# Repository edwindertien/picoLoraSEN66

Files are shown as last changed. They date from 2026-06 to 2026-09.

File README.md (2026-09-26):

# SEN66 Environmental Monitor

A dual-core Raspberry Pi Pico W environmental sensor node, built for indoor
climate monitoring with an eventual path to beehive deployment. Reads
temperature, humidity, CO2, VOC, NOx and particulate matter from a Sensirion
SEN66, exposes a live web dashboard over WiFi, and transmits sensor data over
LoRa for long-range, low-power telemetry.

System architecture

Startup timeline

## Hardware

| Component | Interface | Pins |
|---|---|---|
| Raspberry Pi Pico W | — | RP2040, dual-core |
| Sensirion SEN66 | I2C0 | SDA=GP4, SCL=GP5, addr 0x6B (SEL→GND) |
| Waveshare Pico-LoRa-SX1262 | SPI1 | SCK=GP10, MOSI=GP11, MISO=GP12, CS=GP3, DIO1=GP20, RST=GP15, BUSY=GP2 |
| Waveshare Pico-LCD-1.14 | SPI1 (shared, see below) | SCK=GP10, MOSI=GP11, CS=GP9, DC=GP8, RST=GP12, BL=GP13 |

The LCD and LoRa shields are stacked on the same header and **share SPI1**
(SCK/MOSI) and, critically, **GP12** — the LCD's RST line and the SX1262's
MISO line are the same physical pin, both hardwired with no jumper option.
Only Button B (GP17) on the LCD's joystick/button cluster is free; every
other button/joystick pin (GP2, GP3, GP15, GP20) collides with an SX1262
signal. See "LCD display and SPI1 sharing" below for how this is resolved.

SEN66 measures PM1.0/2.5/4.0/10, relative humidity, temperature, VOC index,
NOx index, and CO2 (SCD4x). CO2 needs roughly 30s from cold start to produce
a valid reading; fan cleaning (optional, ~11s) blows debris out of the PM
optical chamber and should be enabled for any unattended/production
deployment.

## Software stack

- **VSCode + PlatformIO**, `framework = arduino`, `board_build.core = earlephilhower`
- Platform: `https://github.com/maxgerhardt/platform-raspberrypi.git` (provides
  RP2040/Pico W support including LittleFS and `board = rpipicow`)
- Libraries: `Sensirion I2C SEN66`, `ArduinoJson`, `RadioLib`
- LCD driver (`lcd_driver.h`, `lcd_buttons.h`) is a hand-rolled ST7789 tile-buffer
  driver, adapted from an earlier tonewheel-organ project, not a library dependency

## Architecture

The firmware runs genuinely dual-core. **Core 0** owns WiFi, the web server,
the SEN66 over I2C0, the LittleFS log/config, the serial CLI, and the LCD.
**Core 1** owns the SX1262 over SPI1 — once `setup()` on core 0 completes
(including the SEN66 fan-clean delay), it pushes a release value through the
inter-core FIFO so `setup1()` on core 1 can safely initialise SPI1 and the
radio. This ordering matters: starting SPI1 from core 1 before core 0 has
finished its I2C work caused intermittent CRC errors on sensor reads during
development — see `context.md` for that history, and for the much longer
saga of getting the LCD and radio to share SPI1 at all.

```
src/
  main.cpp        setup()/loop() on core 0, setup1()/loop1() on core 1,
                   serial CLI (incl. net/lora commands), SX1262 Module
                   object (owned here)
  sensor.cpp       SEN66 init/read, sentinel-value handling
  config.cpp       LittleFS config.json load/save
  datalog.cpp      CSV ring-buffer log, /history JSON builder
  wifi_mgr.cpp     STA-with-AP-fallback WiFi bring-up
  http_server.cpp  all web handlers + dashboard/config HTML
  lora_wan.cpp     plain LoRa TX/RX, ACK listen window, radio settings,
                   suspend/resume API for the LCD bus handoff
  lcd_display.cpp  ST7789 page rendering, button handling, SPI1
                   release/reclaim on screen off/on

include/           matching headers (lcd_driver.h, lcd_buttons.h are the
                   hand-rolled ST7789/button drivers, not third-party libs)
data/config.json   default config — upload with `pio run --target uploadfs`
```

## LCD display and SPI1 sharing

The LCD and the LoRa radio are both on SPI1, and — unlike a normal
multi-device SPI bus where each device just gets its own CS pin — the LCD's
RST line and the SX1262's MISO line are the **same physical pin (GP12)**,
hardwired with no way to separate them. RST needs to be a Pico-driven output
held high; MISO needs to be the SX1262's own output, which toggles as a
normal part of any SPI transaction. The two roles cannot coexist on one wire
at the same time.

The working solution is a **coarse-grained bus handoff**: the LCD and the
radio never use SPI1 concurrently, not even briefly. Only one of them owns
the bus at any moment, decided by whether the screen is on or off:

- **Screen off** (the default, low-power "LoRa node" state): the radio runs
  normally — `initLoRa()`/`loopLoRa()` on core 1, streaming or CLI-triggered
  TX as configured. The LCD's SPI1 pins (CS, DC, RST, SCK, MOSI) are all
  explicitly set to `INPUT`, so nothing is left driving GP12 except whatever
  the radio needs.
- **Button press wakes the screen**: `lcd_display.cpp` calls
  `lora_request_suspend()`, then polls `lora_is_suspended()` (up to a 3s
  timeout) before touching any pins. Core 1 sees the request at the top of
  its next `loopLoRa()` call, finishes whatever it's doing, puts the radio
  to sleep, releases SPI1, and sets `suspended = true`. Only then does the
  LCD run a **full** `lcd_init()` — not just a pin reconfiguration, the
  complete hardware-reset-pulse-plus-ST7789-init-sequence, since every pin
  was fully released as an input and there's no partial state to build on.
- **Screen times out (20s) or is cycled to OFF**: the LCD releases SPI1
  (`SPI1.end()` + all pins back to `INPUT`) and calls `lora_request_resume()`.
  Core 1 sees the flag clear and calls `initLoRa()` fresh — a complete
  re-init is simpler and more robust than trying to wake the radio from
  `sleep()` with partial state, and this only happens on the rare event of
  a screen transition, so the cost is negligible.

Button B (GP17, the only free pin — see the hardware table above) is
interrupt-driven rather than polled: a plain `digitalRead()` once per
`loop()` iteration was found to miss short taps whenever `loop()` was
briefly busy (a web request, a page render). The interrupt latches the
press the instant it happens, independent of `loop()` timing.

**LCD pages** (`LcdPage` enum in `lcd_display.h`): `SENSOR` → `WIFI` →
`LORA` → six per-channel graph pages → `OFF`, cycling forward on each
Button B press, wrapping back to `SENSOR` after `OFF`. The `LORA` page
shows `suspend` as its state whenever the radio is suspended for the LCD's
own use (which is always true while you're looking at any other page).

See `context.md` for the full, often painful, history of how this
architecture was arrived at — several plausible-looking fixes (mutex
tuning, per-transaction claim/release, forcing a hardware peripheral reset,
defensively deasserting the other device's CS) were tried and ruled out
before the actual fix (coarse-grained mutual exclusion, never concurrent
access) was found.

## Serial CLI

```
help                      command list
status                     full system + LoRa status
read                       single human-readable sensor reading
stream                     toggle CSV stream (Python-monitor compatible)
debug <n>                  0=off 1=web 2=sensor 4=lora 8=bus (OR-able)

net status                 WiFi mode, SSID, IP
net ssid <name>            set WiFi SSID, saved to flash immediately
net pass <password>        set WiFi password, saved to flash immediately
net reconnect              REBOOTS to apply saved SSID/password — see
                            "Network" below for why this must be a reboot

lora status                radio state, TX count, last ACK (shows
                            "suspend" while the LCD screen is on)
lora send                  TX one sensor packet immediately
lora stream on|off         toggle automatic interval TX
lora test <freq> <msg>     one-shot TX on any frequency, any message
lora freq [mhz]            get/set frequency
lora sf <7-12>              set spreading factor
lora power <2-22>          set TX power, dBm
```

`debug 8` (bus) enables diagnostic logging for the LCD/LoRa SPI1 handoff —
leave it off for normal use, turn it on only when debugging screen-on/off
transitions or radio suspend/resume timing.

## Web interface

- `/` — live dashboard: sensor values, LoRa status with live TX countdown,
  tabbed history graphs (selectable channels and time range, axes labelled)
- `/config` — WiFi, logging, LoRa radio and node settings; saves to
  `config.json` and reboots
- `/log` — download the CSV log
- `/clearlog` — wipe the log
- `/data`, `/history`, `/lorastatus`, `/configjson` — JSON API backing the
  above

WiFi starts in STA mode if `wifi_ssid` is set in config, falling back to AP
mode (`SEN66-Monitor` / `sen66pass`, 192.168.4.1) otherwise. Open the
dashboard with `http://` explicitly — some browsers (Firefox) auto-upgrade
bare hostnames to HTTPS, which a local device cannot serve.

## Network

Set or change WiFi credentials from the serial CLI:
```
net ssid myhomewifi
net pass mypassword
net reconnect
```
`net ssid`/`net pass` save to flash immediately but do **not** take effect
live. `net reconnect` genuinely reboots the device (`rp2040.reboot()`)
rather than trying to re-run WiFi setup in place — this is a deliberate
workaround for an arduino-pico core limitation, not a shortcut we took:
`WiFi.status()`/`WiFi.localIP()` both key off an internal `_apMode` flag
that isn't reliably cleared by switching `WiFi.mode()` at runtime once AP
mode has been used, so a live re-init after an AP fallback can report a
fake instant "connected" using the AP's own IP address instead of a real
DHCP lease from your router (see `context.md` and
[earlephilhower/arduino-pico#762](https://github.com/earlephilhower/arduino-pico/issues/762)).
A full reboot is the only reliable way to get a clean STA connection after
the device has ever been in AP mode during the current power cycle.

## LoRa

Two operating modes, set via `lora_mode` is implicit in which CLI/config path
you use — see `lora_wan.cpp`:

- **Plain LoRa** (current, working) — node-ID-prefixed JSON packets
  (`<SEN66-01>{"t":22.3,...}`), private sync word `0x12` so traffic doesn't
  collide with LoRaWAN gateways on the same frequency, 2-second ACK listen
  window after every TX, hardcoded 30s minimum interval as an EU868 duty
  cycle safety floor regardless of configured `lora_interval_s`.
- **LoRaWAN OTAA** (planned, not yet implemented in this codebase) — will
  join via OTAA and send Cayenne LPP payloads to a self-hosted ChirpStack
  gateway, which republishes decoded uplinks to MQTT for Node-RED/Grafana
  consumption.

Config fields: `lora_freq`, `lora_sf`, `lora_bw`, `lora_power`,
`lora_interval_s`, `lora_stream`, `node_id`. LoRaWAN credential fields
(`lora_dev_eui`, `lora_app_eui`, `lora_app_key`) are present in config but
unused until Phase B is built.

## Known limitations / next steps

- LoRaWAN OTAA join is not yet implemented in the current `lora_wan.cpp` —
  only plain peer-to-peer LoRa works today.
- PM optics can read saturated (`0xEB00` sentinel, shown as `SAT` in the UI)
  if the sensor is freshly unboxed, the inlet sticker is still attached, or
  airflow is otherwise obstructed — this is sensor behaviour, not a firmware
  bug.
- The 30s LoRa duty-cycle floor is a flat safety constant, not a proper
  airtime calculation from SF/BW/payload size. Adequate for EU868 at SF9 with
  these short payloads, but should be revisited before scaling to many
  nodes or larger payloads.
- `net reconnect` (and any future WiFi credential change) requires a reboot
  to take effect, by design — see "Network" above. There is currently no
  way to switch STA→AP→STA within one power cycle and get a genuine DHCP
  lease; don't try to "fix" this with a live `startWiFi()` re-init, it's
  been tried and doesn't work on this platform.
- The LCD cannot show live data and the radio cannot transmit at the same
  instant — this is intentional (see "LCD display and SPI1 sharing"), not
  a bug to fix. If simultaneous LCD+radio operation is ever needed, it
  would require moving one of them off SPI1 entirely (e.g. a different LCD
  interface) rather than trying to time-slice the shared bus more finely
  than we already tried and failed to do.
- See `context.md` for the full development/debugging history, including
  several substantial false starts that are deliberately documented so
  they aren't repeated.

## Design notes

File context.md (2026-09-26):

# Development context / handoff notes

This document exists so the next debugging session (human or AI) doesn't
repeat the same dead ends. Read this before changing `lora_wan.cpp`,
`main.cpp`'s core split, `sensor.cpp`'s init sequence, `lcd_display.cpp`/
`lcd_driver.h` (see "The LCD/SPI1 sharing saga" — by far the longest and
most expensive section here), or `wifi_mgr.cpp`'s reconnect behaviour (see
"Network").

## Project phases, in order

1. SEN66 over I2C → serial CSV (Phase 1) — straightforward, worked first try
   once the Sensirion library's `NO_ERROR` macro and integer-vs-float
   signature issues were sorted out.
2. Python live visualiser (`sen66_monitor.py`) — matplotlib, mirrors the
   serial CSV format so it works unchanged against later firmware phases.
3. Web dashboard, AP + STA WiFi, LittleFS config/log, tabbed graph UI
   (Phase 2) — the bulk of the working single-core baseline.
4. Dual-core LoRa integration — this took many iterations to get right; see
   below.
5. Waveshare Pico-LCD-1.14 menu (sensor/WiFi/LoRa status pages, per-channel
   graphs, Button B navigation) — took *even more* iterations, almost all
   of it about sharing SPI1 with the already-working LoRa radio; see "The
   LCD/SPI1 sharing saga" below. This is the single longest debugging arc
   in the project's history — read that section before touching
   `lcd_display.cpp`, `lcd_driver.h`, or the radio suspend/resume API in
   `lora_wan.cpp`.

## The dual-core LoRa saga — what went wrong and why

The single biggest source of wasted time was **CRC errors on SEN66 reads**
that appeared only after LoRa/dual-core code was added, despite the SEN66
sitting on a completely separate bus (I2C0, GP4/GP5) from the LoRa radio
(SPI1, GP10/11/12). Several false theories were chased before finding the
real cause:

### False theory 1: electrical noise from the LoRa shield
Suspected the stacked shield was coupling noise onto the I2C lines, or that
the SX1262 PA current spike was drooping the 3.3V rail enough to glitch I2C.
**Ruled out** — the user confirmed no hardware had changed between a working
single-core build and a failing dual-core build with identical wiring.

### False theory 2: GPIO interrupt collision
GP20 (DIO1, the SX1262 IRQ pin) is also a valid I2C0 SDA alternate function
on the RP2040. Theorised that RadioLib's `attachInterrupt()` on GP20 was
corrupting I2C0 transactions on GP4 via shared interrupt controller state.
Tried `radio.clearDio1Action()` to force polling instead of interrupts.
**Did not fix it** — the CRC errors persisted even with the interrupt
cleared, so this was at most a minor contributor, not the root cause.

### False theory 3: core 1 spinning too fast
Tried `__wfi()`, `sleep_ms()`, and various busy-wait patterns in `loop1()`,
theorising that core 1 polling too aggressively was starving core 0 of bus
cycles. **Did not fix it.**

### Actual root cause: enlarging `Config` and including `config.h` in `sensor.cpp`
The real cause was much simpler and had nothing to do with cores or
interrupts at all: **`sensor.cpp` had gained an `#include "config.h"`**
during a refactor that added LoRa fields to the `Config` struct. Enlarging
`Config` changed stack/memory layout in a way that corrupted something
adjacent — likely the ArduinoJson `JsonDocument` or the SEN66 I2C read
buffer — when both were compiled in the same translation unit as the now-
larger struct.

**The fix:** `sensor.cpp` must never include `config.h`. Anything `sensor.cpp`
needs from config (e.g. whether to run fan cleaning) is passed in as a plain
function parameter from `main.cpp`, which does have `config.h`:

```cpp
// sensor.h
void initSensor(bool doFanCleaning = true);

// main.cpp
initSensor(cfg.fan_cleaning);
```

This was confirmed by diffing against a known-good single-core project
(`picoSEN66_3`) file-by-file and restoring files verbatim, then re-adding
LoRa support field-by-field while explicitly checking `sensor.cpp` for stray
includes after every change.

**Lesson for future work:** if CRC/I2C errors reappear after adding fields
to `Config`, check `sensor.cpp`'s includes before suspecting hardware,
interrupts, or core timing. It is tempting to blame dual-core because the
symptom only appeared after dual-core was introduced, but the actual trigger
was a coincident refactor, not the cores themselves.

### SPI1 init pattern that actually works

Earle Philhower's `SPIClassRP2040` (not `arduino::MbedSPI` — that class
doesn't exist in this core, despite appearing in some other projects'
examples found online) needs pins set individually before `begin()`:

```cpp
SPI1.setRX(12);     // MISO
SPI1.setTX(11);     // MOSI
SPI1.setSCK(10);    // SCK
SPI1.begin(false);  // false = software/manual CS; RadioLib drives CS (GP3)
                     // directly as a GPIO, so setCS() is never called
```

Calling `setCS()` was tried and is unnecessary — RadioLib's `Module`
constructor takes the CS pin directly and manages it itself.

**Ownership rule that was eventually settled on:** all SPI1 setup
(`setRX/setTX/setSCK/begin`) and `radio.begin()` happen together on **core
1**, inside `setup1()`, gated by `rp2040.fifo.pop()` so core 1 doesn't touch
SPI1 until core 0 has explicitly signalled (via `rp2040.fifo.push()`) that
its own setup — including the SEN66 fan-clean delay — is fully complete.
Earlier attempts split SPI1 init across both cores or ran it before core 0
finished; both caused hangs or the CRC corruption above.

### `radio.begin()` parameter gotchas

- Calling `radio.begin()` with explicit TCXO voltage (`tcxoVoltage` param)
  caused indefinite hangs on this Waveshare module — it sends a
  `SetDIO3AsTCXOCtrl` command and waits for oscillator lock that never
  completes on this hardware. **Fix:** call `radio.begin()` with no
  arguments (defaults), then explicitly call `setFrequency`, `setBandwidth`,
  `setSpreadingFactor`, `setCodingRate`, `setSyncWord`, `setOutputPower`
  afterward.
- `radio.setDio2AsRfSwitch(true)` is required for this module's RF switch
  wiring.
- RadioLib's `LoRaWANNode::beginOTAA()` signature changed between major
  versions — v6.x takes `uint64_t joinEUI, uint64_t devEUI, uint8_t* nwkKey,
  uint8_t* appKey` and returns `void` (not `int16_t`). EUIs must be parsed
  from hex strings to `uint64_t`, not byte arrays, for this call.

## Duty cycle / interval bug

`lora_interval_s` in config and a separate hardcoded `MIN_INTERVAL_MS`
(originally 30000) were both gating LoRa stream timing, and at one point a
manual `lora send` CLI command was *also* gated by the same 30s floor,
making manual testing feel like the firmware was "hanging" for half a minute
on every test send. Resolved by keeping the 30s floor as a safety constant
for **automatic stream mode only** — manual `lora send`/`lora test` should
remain ungated for responsive testing, *however* the user's preference,
confirmed in conversation, was to keep `lora send` gated too (so the
behaviour matches stream mode exactly) once duty cycle and config interval
mismatches were untangled. Current behaviour: `lora send` respects
`dutyOk()`; only `lora test` (explicit one-shot with arbitrary frequency)
bypasses it.

## `lora test` vs `lora send` payload difference

Early in testing, `lora test <freq> <quoted-json>` worked (verified on a
spectrum analyser) while `lora send` did not appear to arrive at the
gateway, despite both reporting `TX OK` at the radio level. Investigation
showed:
- Frequency, SF, BW, and power were identical for both paths once `cfg.lora_freq`
  was set to match the test frequency permanently (rather than being
  temporarily overridden and restored by `lora test`'s save/restore logic).
- The actual unresolved variable when this was last discussed was the
  **30-second duty-cycle wait** being mistaken for a hang — `lora send`
  appeared to "block" because the CLI was reporting `[lora] Duty cycle: wait
  Xs` and the user was watching it count down, not because of a code defect.
  **Status: revisit this if it recurs** — the immediate suspects (frequency
  drift, payload encoding, quoting artefacts) were all ruled out, but a full
  root-cause was not conclusively nailed down before the session moved on to
  other features. If `lora send` silently fails to reach the gateway again,
  capture the gateway-side raw packet log (frequency, SF, payload bytes) for
  a TX that the firmware reports as successful, and compare byte-for-byte
  against a known-good `lora test` packet.

## SEN66 fan cleaning / sensor warm-up

- CO2 (SCD4x inside the SEN66) needs **roughly 30 seconds** from cold start
  to produce a non-sentinel reading — this is sensor physics, not a
  firmware bug. Don't chase "CO2 reads 0/0xFFFF" issues for the first
  30-60s after boot.
- Fan cleaning (`startFanCleaning()`, ~11s) was originally unconditional;
  made it a config-controlled boolean (`fan_cleaning`, default `true`) so it
  can be disabled during rapid iterate-flash-test debugging cycles without
  losing 11 seconds every boot. **Always re-enable for real deployment** —
  without it, PM optics accumulate debris over time.
- One debugging session found the fan was *not spinning* despite
  `startFanCleaning()` reporting no I2C error. Root cause was that
  `startContinuousMeasurement()`'s return value wasn't being checked/logged
  loudly enough to notice it had failed; once explicit
  `Serial.println("[sen66] startContinuousMeasurement OK")` /
  `"FATAL: measurement not started"` logging was added, the failure became
  visible immediately. Always check this log line first if gas-sensor
  channels read zero indefinitely past the 30-60s warm-up window.
- An I2C bus scan (addresses 1-127) was added to `initSensor()` for the same
  reason — confirms the SEN66 is physically present at `0x6B` before doing
  anything else, removing wiring/address as a variable early.

## Files restored from a known-good snapshot

At one point the project was reset to a known-working baseline
(`picoSEN66_3`, single-core, no LoRa) after too many compounding theories
made the dual-core+LoRa debugging session unproductive. All `src/*.cpp` and
`include/*.h` files were diffed and copied verbatim from that baseline
before LoRa was re-added incrementally, one verified step at a time:
1. Dual-core skeleton, core 1 idle (`sleep_ms` only) — confirmed sensor
   still worked.
2. SPI1 pin setup + `begin()` on core 1 — confirmed no hang.
3. `radio.begin()` added — confirmed `SX1262 OK`.
4. CLI-triggered single test TX (`lora test`) — confirmed over spectrum
   analyser.
5. Full plain-LoRa implementation with ACK window, stream mode, settings
   commands.

If dual-core/LoRa breaks again in a way that resists debugging, this
incremental rebuild path (idle core → SPI → radio.begin → manual TX →
full feature) is the fastest way back to a working state — faster than
trying to debug forward from a broken full-featured state.

## The LCD/SPI1 sharing saga

Adding a Waveshare Pico-LCD-1.14 (for a menu of sensor/WiFi/LoRa status
pages plus per-channel graphs) turned into by far the longest debugging
arc in this project — much longer than the dual-core CRC saga above. This
section exists specifically so nobody re-tries the things that were
already tried and ruled out.

### The core physical constraint

The LCD and the SX1262 both sit on SPI1. Sharing SCK/MOSI with separate CS
pins is completely normal and was never the issue. The actual problem is
that **the LCD's RST pin and the SX1262's MISO pin are the same physical
wire (GP12)**, hardwired on both shields with no jumper to separate them.
RST needs to be a Pico output held HIGH; MISO needs to be the SX1262's own
output, which necessarily toggles as part of any normal SPI transaction.
These two roles are fundamentally incompatible on one wire at the same
time — this was eventually understood to be an *electrical* constraint,
not something any amount of clever software timing could paper over.

### Symptom, for a long stretch: "radio works, LCD shows nothing" or vice versa

For many iterations, exactly one of the two would work at a time, and
fixing one reliably broke the other. Everything below was tried, in
roughly this order, while chasing that symptom:

1. **Mutex timing** (`mutex_init()` too late, blocking vs
   `mutex_try_enter`) — no effect on the underlying problem. A flush-
   success/skip counter was added at one point and showed **thousands of
   successful tile flushes with zero visible content** — proof that "the
   function call completed" and "the display actually updated" are not
   the same thing, and that mutex contention was never the bottleneck.
2. **SPI clock speed not being restored** between the LCD's 62.5MHz and
   RadioLib's 2MHz — tried manual `beginTransaction`/`endTransaction`
   restores, then a `radio.setSPISettings()` call that doesn't exist on
   `SX1262` (compile error, reverted), then a manual `spi1_radio_speed()`
   helper. No effect.
3. **GP12 pin-restore mechanism** — tried `SPI1.setRX()` + a second
   `begin()`, then the raw SDK `gpio_set_function()` call instead. Radio
   reliability tracked with *whether the radio ran at all*, not with which
   restore mechanism was used — this was a real clue that got
   under-weighted at the time.
4. **Double `SPI1.begin()` from both cores** — a real and worth-
   remembering finding: SPI1 is **one physical peripheral**, not
   duplicated per core, and having both core 0 (LCD) and core 1 (radio)
   independently call `begin()` does re-initialise the shared block out
   from under whichever side didn't call it last. Removing the second
   `begin()` (radio trusting the LCD's earlier init) fixed radio
   reliability — but the LCD *still* showed nothing afterward, which in
   hindsight proved this was never sufficient on its own.
5. **Full claim/release around every single operation**
   (`SPI1.end()`→reconfigure→`begin()`→work→`end()`, both sides,
   symmetric) — implemented thoroughly, including a genuine RP2040
   `reset_block(RESETS_RESET_SPI1_BITS)`/`unreset_block_wait(...)`
   hardware peripheral reset (not just the `SPI1.end()`/`begin()` Arduino
   wrapper, which does not guarantee every internal register returns to
   power-on defaults). Radio kept working; LCD still showed nothing.
6. **Defensively deasserting the other device's CS** before every claim
   (force GP3 HIGH before an LCD transfer, GP9 HIGH before a radio
   transfer) — on the theory that a stuck-low CS was letting the SX1262
   "listen in" on LCD traffic and corrupt it. No change.
7. **RadioLib's DIO1 interrupt** — `radio.clearDio1Action()` had been
   added, then lost, then re-added; a genuinely different mechanism from
   everything else (an ISR firing outside the mutex model entirely), but
   also made no difference to the LCD-blank symptom specifically.

### The reset that actually mattered: going back to a known-good baseline

After enough failed fixes, the productive move was to **stop iterating on
the broken integrated system** and rebuild forward from a state that was
provably correct:

1. Restored `lcd_driver.h`'s `lcd_init()` to the exact version that had
   been confirmed rendering correctly early on — the LCD calling its
   **own** `SPI1.begin()` (no arguments — hardware CS mode), with a real
   hardware RST pulse on GP12. This intentionally reintroduces the GP12
   conflict, on the theory that the *sharing model*, not this specific
   pin, was the real problem.
2. Rebuilt `lcd_display.cpp` from scratch as a deliberately minimal,
   single-core-only baseline: no radio code compiled in at all (`main.cpp`
   with an empty `setup1()`/`loop1()`, `lora_wan.cpp` moved out of `src/`
   entirely so it isn't even linked). Confirmed the LCD worked reliably,
   permanently on, through many pages and power cycles, with radio fully
   out of the picture.
3. Added the screen timeout and OFF-page cycling *before* touching the
   radio again, confirming the LCD's own release-to-`INPUT` and full-
   `lcd_init()`-on-wake cycle was solid in isolation — still zero radio
   involvement.
4. Only then reintroduced LoRa, with a **coarse-grained bus handoff**
   instead of any of the fine-grained per-transaction sharing tried
   before: the LCD and radio never touch SPI1 concurrently, not even
   briefly. Whoever isn't currently "in control" doesn't merely yield the
   bus for a moment — it's either fully active or fully torn down
   (`SPI1.end()` + every pin to `INPUT` on the LCD side; `radio.sleep()`
   + release on the radio side), with a simple request/acknowledge flag
   pair (`lora_request_suspend()`/`lora_is_suspended()`/
   `lora_request_resume()`) governing the handoff. This is the
   architecture described in the README and is what actually works.

**The lesson, stated plainly:** fine-grained interleaving of two devices
on a bus that share a physical pin with genuinely incompatible signal
roles cannot be made to work by better mutex discipline, faster resets, or
more careful timing — no matter how many different mechanisms you try. It
needs coarse-grained mutual exclusion: one owner at a time, full teardown
on handoff, never both "on" simultaneously even for a moment.

### Two compounding bugs that wasted significant time mid-saga

- **A file mix-up**: at one point `src/lcd_display.cpp` on the user's
  actual disk had accidentally ended up containing `main.cpp`'s content
  (duplicate `setup()`/`loop()`, global variables, linker errors like
  "multiple definition of `staMode`"). This produced confusing symptoms
  that looked like a code regression but were actually just the wrong
  file being compiled. **Lesson**: when behaviour doesn't match what the
  source clearly says it should do, check for a stale build or a
  misplaced file *before* forming a new theory about the code's logic.
- **A leftover diagnostic flag**: `LORA_FULLY_DISABLED` (added
  temporarily to isolate whether LoRa activity was blocking LCD
  rendering) was left defined for several turns after it had served its
  purpose, causing `lora_is_suspended()` to unconditionally return `true`
  and completely masking the real suspend/resume logic — producing
  exactly the "LCD always active, radio always suspended" symptom, with
  no relation to the actual bug being chased at the time. **Lesson**:
  temporary isolation flags need to be actively removed, not just left
  commented-out-by-default, and their effect should be the first thing
  checked when a symptom looks suspiciously absolute ("always", "never").

### Smaller fixes bundled into the same rebuild

- **Button B polling missed short presses.** A plain `digitalRead()` once
  per `loop()` iteration can miss a tap that starts and ends between two
  loop iterations, if `loop()` happens to be briefly busy (a web request,
  a page render's SPI transfer). Switched to `attachInterrupt()` with a
  50ms debounce inside the ISR itself — the press is latched the instant
  it happens, independent of `loop()` timing.
- **The OFF page was unreachable.** The page-cycle wrap logic checked "did
  we overflow past `PAGE_COUNT`, if so reset to `SENSOR`" *before*
  checking "did we land exactly on `OFF`" — so the overflow check always
  fired first and the OFF-check could never be reached. Fixed with a
  plain modulo wrap (`OFF` is enum value `0`, so `(current + 1) %
  PAGE_COUNT` lands there correctly on its own).
- **Default boot state changed** to screen-off/backlight-off/LoRa-active
  — the device is meant to operate as a low-power LoRa node most of the
  time, with the screen only for occasional interactive checks. The LCD
  hardware isn't even touched at boot now (no `lcd_init()` call at all
  until the first button press) specifically so the radio gets a
  completely untouched SPI1 peripheral as its first-ever user.

## Network: `_apMode` and why `net reconnect` must reboot

Adding `net ssid`/`net pass`/`net reconnect` CLI commands surfaced a
genuine arduino-pico core bug, not an application-level mistake:
[earlephilhower/arduino-pico#762](https://github.com/earlephilhower/arduino-pico/issues/762).
`WiFiClass::status()` and `WiFiClass::localIP()` both decide which
physical interface (STA vs AP) to report on via an internal `_apMode`
boolean, which is not reliably cleared by calling `WiFi.mode()` at
runtime once AP mode has been used. Symptom observed directly: after a
STA-failed→AP-fallback at boot, calling `net reconnect` (which re-ran
`startWiFi()` live) produced:
```
[wifi] Trying STA: voorhuis
[wifi] Connected! IP: 192.168.42.1
```
— note zero connection-attempt dots (a real STA handshake takes at least
a few hundred ms; here `WL_CONNECTED` was reported instantly) and an IP
identical to the AP's own address, not a real DHCP lease from the router.
Things tried that did **not** fix it: `WiFi.disconnect(true)` before
retrying (helped nothing since the flag itself wasn't touched),
`WiFi.softAPdisconnect(true)` + `WiFi.mode(WIFI_OFF)` + a settling delay
before retrying STA (still no change — `_apMode` apparently isn't cleared
by any combination of these calls). **The only fix that actually works**:
`net reconnect` now calls `rp2040.reboot()` outright. A full reboot
reinitialises the WiFi driver and its `_apMode` flag from a genuinely
clean state; nothing short of that was found to be reliable. Don't spend
time trying to find a live-reinit workaround again without checking
whether upstream has fixed the underlying issue first.

## Outstanding / not yet built

- LoRaWAN OTAA join + Cayenne LPP uplinks (Phase B) — config fields exist,
  implementation does not yet.
- ChirpStack gateway setup, MQTT integration, Node-RED/Grafana consumption —
  not started.
- Proper duty-cycle calculation from SF/BW/payload size (currently a flat
  30s constant).
- The `lora test` vs `lora send` gateway-arrival discrepancy noted above —
  inconclusively resolved, revisit if it recurs.
- Joystick/A-button support while the screen is on: now that the radio is
  fully suspended (and its pins inert) whenever the LCD is active, GP2/GP3/
  GP15/GP20 are technically free for the joystick during that window —
  this was identified as a natural follow-on but not yet implemented. Would
  need those pins reconfigured to `INPUT_PULLUP` on wake and handed back to
  the radio's expected states on sleep, mirroring what's already done for
  the LCD's own pins.
- LCD/radio genuinely simultaneous operation is not supported by design
  (see "LCD display and SPI1 sharing" in the README) — don't attempt to
  relax this without first re-reading the saga above.

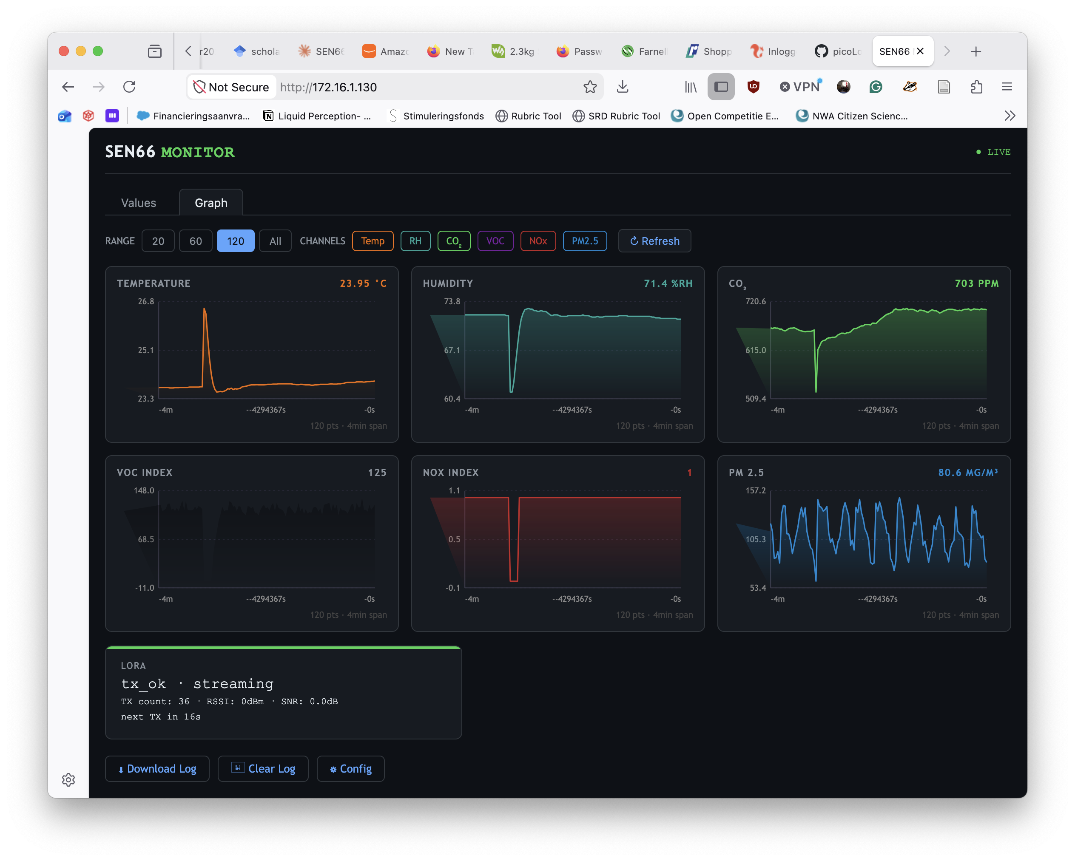
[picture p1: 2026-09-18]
docs/interface.png

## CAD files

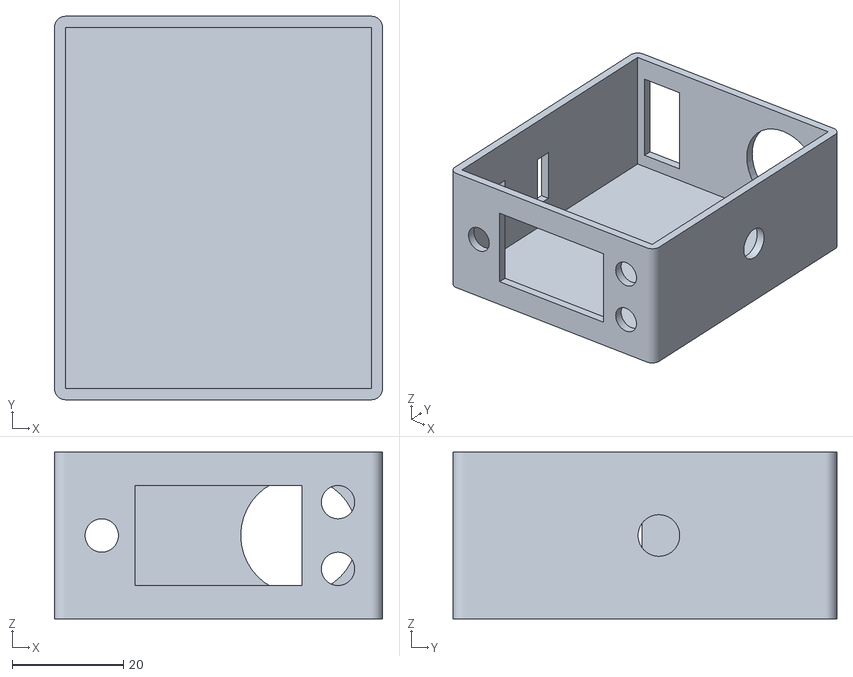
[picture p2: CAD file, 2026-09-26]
design/box.stl
59.0 x 69.0 x 30.0

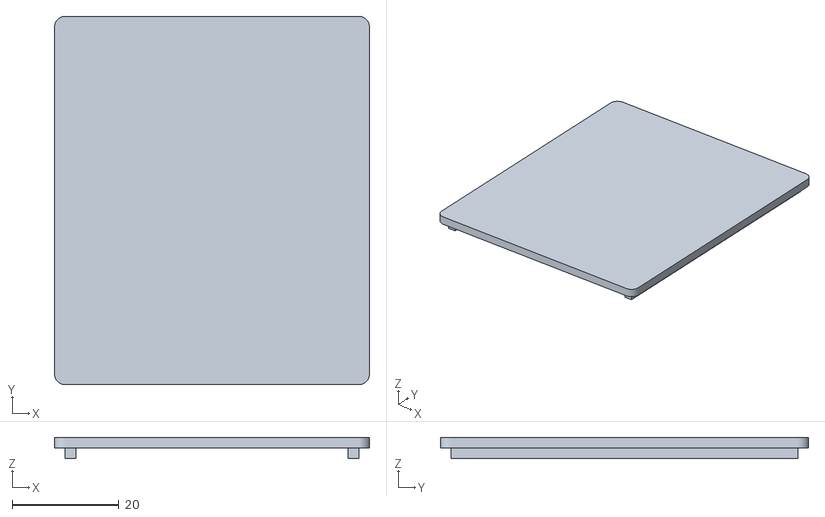
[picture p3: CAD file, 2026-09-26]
design/lid.stl
59.0 x 69.0 x 4.00

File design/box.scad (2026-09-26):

$fn=40;

box(55,65,28,2);

//translate([0,0,40])lid(55,70,2);

module box(width, depth, height,wall){
difference(){
    hull(){
        translate([0,depth,0])cylinder(r=wall,h=height+wall);
        translate([width,depth,0])cylinder(r=wall,h=height+wall);
        translate([width,0,0])cylinder(r=wall,h=height+wall);
        translate([0,0,0])cylinder(r=wall,h=height+wall);
    }
    translate([0,0,wall])cube([width,depth,height+wall]);
    
    translate([42,50,15])rotate([-90,0,0])cylinder(d=21,h=30);
    translate([2,50,5])cube([10,30,20]);
    
    translate([12.5,-5,6])cube([30,30,18]);
    
    translate([49,-5,9])rotate([-90,0,0])cylinder(d=6,h=30);
    translate([49,-5,21])rotate([-90,0,0])cylinder(d=6,h=30);
    translate([6.5,-5,15])rotate([-90,0,0])cylinder(d=6,h=30);
    translate([-5,28,8])cube([20,4,12]);
    translate([-5,12,12])cube([20,4,8]);
    
    translate([25,35,15])rotate([0,90,0])cylinder(d=7.5,h=50);
}
}


module lid(width, depth,wall){
difference(){
    hull(){
        translate([0,depth,0])cylinder(r=wall,h=wall);
        translate([width,depth,0])cylinder(r=wall,h=wall);
        translate([width,0,0])cylinder(r=wall,h=wall);
        translate([0,0,0])cylinder(r=wall,h=wall);
    }
}
difference(){
translate([0,0,-wall])cube([width,depth,wall]);
    translate([wall,0,-wall])cube([width-2*wall,depth,wall]);
}
}

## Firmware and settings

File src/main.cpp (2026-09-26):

// ═══════════════════════════════════════════════════════════════════════════
// SEN66 Monitor — Step 3: LCD + LoRa reintegrated
// Core 0: WiFi, web, sensor, serial CLI, LCD
// Core 1: LoRa — suspended/resumed via coarse-grained bus handoff whenever
//         the LCD screen is on/off (see lora_request_suspend/resume calls
//         in lcd_display.cpp's screen_on_page()/screen_off()).
// ═══════════════════════════════════════════════════════════════════════════
#include <Arduino.h>
#include <LittleFS.h>
#include <WiFi.h>
#include <WebServer.h>
#include <SPI.h>
#include <RadioLib.h>

#include "globals.h"
#include "config.h"
#include "sensor.h"
#include "datalog.h"
#include "wifi_mgr.h"
#include "http_server.h"
#include "lora_wan.h"
#include "lcd_display.h"

uint8_t  debugLevel    = 0;
bool     streamEnabled = false;
bool     staMode       = false;
uint32_t lastLogTime   = 0;

// ── SX1262 radio object — owned by core 1 ────────────────────────────────
// Waveshare Pico-LoRa-SX1262: CS=3, DIO1=20, RST=15, BUSY=2
SX1262 radio = new Module(3, 20, 15, 2, SPI1);

// ── Core 1: LoRa ──────────────────────────────────────────────────────────
void setup1() {
    rp2040.fifo.pop();          // wait for core 0 to finish its own setup
    initLoRa();                 // claims SPI1 itself, internally
}

void loop1() {
    loopLoRa();
    sleep_ms(50);
}

// ── Serial CLI ────────────────────────────────────────────────────────────
static void printHelp() {
    Serial.println("─────────────────────────────────────────────");
    Serial.println(" SEN66 Serial CLI");
    Serial.println("  help              — this message");
    Serial.println("  status            — system status");
    Serial.println("  read              — single sensor reading");
    Serial.println("  stream            — toggle CSV serial stream");
    Serial.println("  debug <n>         — 0=off 1=web 2=sensor 4=lora 8=bus");
    Serial.println(" ── Network ───────────────────────────────────");
    Serial.println("  net status        — WiFi mode, SSID, IP");
    Serial.println("  net ssid <name>   — set WiFi SSID (saved)");
    Serial.println("  net pass <pwd>    — set WiFi password (saved)");
    Serial.println("  net reconnect     — reboot to apply saved SSID/pass");
    Serial.println(" ── LoRa ──────────────────────────────────────");
    Serial.println("  lora status       — radio state, last ACK");
    Serial.println("  lora send         — TX one sensor packet now");
    Serial.println("  lora stream on    — auto TX at interval");
    Serial.println("  lora stream off   — stop auto TX");
    Serial.println("  lora test <freq> <msg>  — one-shot test TX");
    Serial.println("    e.g.  lora test 868.75 hello world");
    Serial.println("  lora freq <mhz>   — set frequency");
    Serial.println("  lora sf <7-12>    — set spreading factor");
    Serial.println("  lora power <dbm>  — set TX power (2-22)");
    Serial.println("─────────────────────────────────────────────");
}

static void printStatus() {
    FSInfo fs; LittleFS.info(fs);
    Serial.println("─────────────────────────────────────────────");
    Serial.printf(" WiFi:    %s  IP: %s\n", staMode ? "STA" : "AP",
        staMode ? WiFi.localIP().toString().c_str()
                : WiFi.softAPIP().toString().c_str());
    Serial.printf(" Uptime:  %lus\n", millis()/1000);
    Serial.printf(" Flash:   %u/%u bytes\n", fs.usedBytes, fs.totalBytes);
    Serial.printf(" Log:     %lu rows\n", logRowCount);
    Serial.printf(" Debug:   %u\n", debugLevel);
    Serial.println(" ── LoRa ──────────────────────────────────────");
    Serial.printf(" State:   %s%s\n", loraStateStr(),
        lora_is_suspended() ? " (suspended — LCD active)" : "");
    Serial.printf(" Node:    %s\n", cfg.node_id);
    Serial.printf(" Freq:    %.3f MHz\n", cfg.lora_freq);
    Serial.printf(" SF/BW:   SF%u / %.0f kHz\n", cfg.lora_sf, cfg.lora_bw);
    Serial.printf(" Power:   %d dBm\n", cfg.lora_power);
    Serial.printf(" Stream:  %s  interval=%us\n",
        loraStreaming ? "ON" : "OFF", cfg.lora_interval_s);
    Serial.printf(" TX count:%lu\n", loraTxCount);
    if (loraStreaming && !lora_is_suspended()) {
        uint32_t intervalMs = max((uint32_t)cfg.lora_interval_s * 1000UL, 30000UL);
        uint32_t elapsed = millis() - loraLastTxMs;
        if (elapsed < intervalMs)
            Serial.printf(" Next TX: %lus\n", (intervalMs - elapsed) / 1000);
        else
            Serial.println(" Next TX: due now");
    }
    if (loraLastAck.length() > 0)
        Serial.printf(" Last ACK: \"%s\"  RSSI=%d  SNR=%.1f\n",
            loraLastAck.c_str(), loraLastRssi, loraLastSnr);
    Serial.println("─────────────────────────────────────────────");
}

static void handleSerial() {
    if (!Serial.available()) return;
    String cmd = Serial.readStringUntil('\n');
    cmd.trim();
    String cmdL = cmd; cmdL.toLowerCase();

    if      (cmdL == "help")   printHelp();
    else if (cmdL == "status") printStatus();
    else if (cmdL == "read") {
        if (latest.valid) printReadable(latest);
        else Serial.println("[cli] No reading yet");
    }
    else if (cmdL == "stream") {
        streamEnabled = !streamEnabled;
        Serial.printf("[cli] Serial stream %s\n", streamEnabled ? "ON" : "OFF");
        if (streamEnabled)
            Serial.println("ts_ms,pm1.0,pm2.5,pm4.0,pm10,rh_%,temp_C,voc_idx,nox_idx,co2_ppm");
    }
    else if (cmdL.startsWith("debug")) {
        String arg = cmdL.substring(5); arg.trim();
        if (arg.length() > 0) {
            debugLevel = (uint8_t)arg.toInt();
            Serial.printf("[cli] Debug → %u\n", debugLevel);
        }
    }
    // ── Network commands ─────────────────────────────────────────────────
    else if (cmdL == "net status") {
        Serial.printf("[net] mode=%s  IP=%s  SSID='%s'\n",
            staMode ? "STA" : "AP",
            staMode ? WiFi.localIP().toString().c_str()
                    : WiFi.softAPIP().toString().c_str(),
            staMode ? cfg.wifi_ssid : cfg.ap_ssid);
    }
    else if (cmdL.startsWith("net ssid ")) {
        String ssid = cmd.substring(9);  // preserve case
        ssid.trim();
        if (ssid.length() == 0 || ssid.length() >= sizeof(cfg.wifi_ssid)) {
            Serial.println("[net] Invalid SSID length"); return;
        }
        strlcpy(cfg.wifi_ssid, ssid.c_str(), sizeof(cfg.wifi_ssid));
        if (saveConfig()) Serial.printf("[net] SSID set to '%s' and saved. Run 'net reconnect' to apply.\n", cfg.wifi_ssid);
        else Serial.println("[net] SSID set but save FAILED");
    }
    else if (cmdL.startsWith("net pass ")) {
        String pass = cmd.substring(9);  // preserve case
        if (pass.length() >= sizeof(cfg.wifi_pass)) {
            Serial.println("[net] Password too long"); return;
        }
        strlcpy(cfg.wifi_pass, pass.c_str(), sizeof(cfg.wifi_pass));
        if (saveConfig()) Serial.println("[net] Password set and saved. Run 'net reconnect' to apply.");
        else Serial.println("[net] Password set but save FAILED");
    }
    else if (cmdL == "net reconnect") {
        // A live re-init (calling startWiFi() again without rebooting)
        // is unreliable on this platform: the arduino-pico WiFi library
        // tracks an internal _apMode flag that WiFi.mode() does not
        // reliably clear once AP mode has been used, causing
        // WiFi.status()/WiFi.localIP() to keep reporting the AP
        // interface's state forever, regardless of what mode is
        // requested afterward (a known upstream issue). A full reboot
        // is the only way to guarantee a clean WiFi driver state.
        Serial.println("[net] Rebooting to apply network settings...");
        delay(200);
        rp2040.reboot();
    }
    // ── LoRa commands ─────────────────────────────────────────────────────
    else if (cmdL == "lora status") {
        printStatus();
    }
    else if (cmdL == "lora send") {
        if (lora_is_suspended()) { Serial.println("[cli] Radio suspended (LCD active) — try again after screen off"); return; }
        loraSendSensor();
        Serial.println("[cli] Sensor TX queued");
    }
    else if (cmdL == "lora stream on") {
        loraStreaming = true;
        Serial.printf("[cli] LoRa stream ON — interval %us\n", cfg.lora_interval_s);
    }
    else if (cmdL == "lora stream off") {
        loraStreaming = false;
        Serial.println("[cli] LoRa stream OFF");
    }
    else if (cmdL.startsWith("lora test ")) {
        if (lora_is_suspended()) { Serial.println("[cli] Radio suspended (LCD active) — try again after screen off"); return; }
        String rest = cmd.substring(10);
        int sp = rest.indexOf(' ');
        if (sp < 0) { Serial.println("[cli] Usage: lora test <freq> <message>"); return; }
        float freq = rest.substring(0, sp).toFloat();
        String msg = rest.substring(sp + 1);
        if (freq < 100.0 || freq > 1000.0) {
            Serial.println("[cli] Invalid frequency"); return;
        }
        Serial.printf("[cli] Test TX @ %.3f MHz: %s\n", freq, msg.c_str());
        loraSendTest(freq, msg);
    }
    else if (cmdL == "lora freq") {
        Serial.printf("[lora] Current frequency: %.3f MHz\n", cfg.lora_freq);
    }
    else if (cmdL.startsWith("lora freq ")) {
        float freq = cmdL.substring(10).toFloat();
        if (freq < 100.0 || freq > 1000.0) { Serial.println("[cli] Invalid frequency"); return; }
        cfg.lora_freq = freq;
        loraSetFreq(freq);
    }
    else if (cmdL.startsWith("lora sf ")) {
        uint8_t sf = (uint8_t)cmdL.substring(8).toInt();
        cfg.lora_sf = sf;
        loraSetSF(sf);
    }
    else if (cmdL.startsWith("lora power ")) {
        int8_t pwr = (int8_t)cmdL.substring(11).toInt();
        cfg.lora_power = pwr;
        loraSetPower(pwr);
    }
    else if (cmd.length() > 0)
        Serial.printf("[cli] Unknown: '%s'  (try 'help')\n", cmd.c_str());
}

// ── Core 0 ────────────────────────────────────────────────────────────────
extern mutex_t spi1_mutex;

void setup() {
    mutex_init(&spi1_mutex);

    Serial.begin(115200);
    delay(2000);
    Serial.println("\n═══ SEN66 Monitor — Step 3: LCD + LoRa ═══");

    if (!LittleFS.begin()) { LittleFS.format(); LittleFS.begin(); }
    Serial.println("[fs] mounted");

    loadConfig();
    initLog();
    startWiFi();
    setupWebServer();
    initSensor(cfg.fan_cleaning);
    lcd_display_init();

    printHelp();
    Serial.println("[boot] Complete — signalling core 1");
    rp2040.fifo.push(0xAA55AA55);
}

void loop() {
    server.handleClient();
    handleSerial();
    lcd_display_handle_buttons();
    lcd_display_update();

    static uint32_t lastReadMs = 0;
    if (millis() - lastReadMs >= 1000) {
        lastReadMs = millis();
        readSensor(latest);
        if (latest.valid)
            lcd_push_reading(latest.temp, latest.rh, (float)latest.co2,
                             latest.voc, latest.nox,
                             latest.pm_sat ? 0.0f : latest.pm25);
        if (streamEnabled && latest.valid)
            printMeasurement(latest);
    }

    if (latest.valid &&
        millis() - lastLogTime >= (uint32_t)cfg.interval_s * 1000) {
        lastLogTime = millis();
        appendLog(latest);
    }

    // ── LoRa stream countdown ticker — one dot per second on a single
    // line, only while streaming AND not suspended for LCD use.
    static uint32_t lastCountdownMs = 0;
    static bool     countdownLineOpen = false;
    if (loraStreaming && !lora_is_suspended() && millis() - lastCountdownMs >= 1000) {
        lastCountdownMs = millis();
        uint32_t intervalMs = max((uint32_t)cfg.lora_interval_s * 1000UL, 30000UL);
        uint32_t elapsed = millis() - loraLastTxMs;
        if (elapsed < intervalMs) {
            if (!countdownLineOpen) {
                Serial.print("[lora] next TX ");
                countdownLineOpen = true;
            }
            Serial.print(".");
        }
    }
    if (countdownLineOpen && (!loraStreaming || lora_is_suspended() ||
        millis() - loraLastTxMs >= max((uint32_t)cfg.lora_interval_s * 1000UL, 30000UL))) {
        Serial.println();
        countdownLineOpen = false;
    }
}

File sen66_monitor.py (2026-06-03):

#!/usr/bin/env python3
"""
sen66_monitor.py — Live serial visualiser for SEN66 Phase 1 firmware
Requires: pip install pyserial matplotlib

Usage:
    python sen66_monitor.py              # auto-detects port
    python sen66_monitor.py COM3         # Windows
    python sen66_monitor.py /dev/ttyACM0 # Linux
"""

import sys
import argparse
import threading
import collections
import time
from datetime import datetime

import serial
import serial.tools.list_ports
import matplotlib
#matplotlib.use("TkAgg")          # explicit backend — avoids macOS animation stall
matplotlib.use("MacOSX")
import matplotlib.pyplot as plt
import matplotlib.animation as animation
from matplotlib.gridspec import GridSpec

# ── Config ────────────────────────────────────────────────────────────────────
BAUD        = 115200
WINDOW      = 120        # seconds of history to show
POLL_MS     = 500        # plot refresh (ms) — 500 ms is plenty, reduces GUI load
HEADER      = "ts_ms,pm1.0,pm2.5,pm4.0,pm10,rh_%,temp_C,voc_idx,nox_idx,co2_ppm"
COLS        = HEADER.split(",")

# SEN66 PM saturation value (not the same as UINT16 sentinel 0xFFFF)
# 0xEB00 / 10 = 6016.0  — sensor is overwhelmed / obstructed
PM_SATURATED = 6016.0

COLORS = {
    "pm1.0":   "#4fc3f7",
    "pm2.5":   "#0288d1",
    "pm4.0":   "#01579b",
    "pm10":    "#b71c1c",
    "rh_%":    "#26a69a",
    "temp_C":  "#ef6c00",
    "voc_idx": "#7b1fa2",
    "nox_idx": "#c62828",
    "co2_ppm": "#2e7d32",
}

RANGES = {
    "pm1.0":   (0,    1999,  "µg/m³"),
    "pm2.5":   (0,    1999,  "µg/m³"),
    "pm4.0":   (0,    1999,  "µg/m³"),
    "pm10":    (0,    1999,  "µg/m³"),
    "rh_%":    (0,    100,   "%RH"),
    "temp_C":  (-20,  60,    "°C"),
    "voc_idx": (0,    500,   "idx"),
    "nox_idx": (0,    500,   "idx"),
    "co2_ppm": (300,  5000,  "ppm"),
}

# ── Data store ────────────────────────────────────────────────────────────────
maxlen   = WINDOW * 2
data     = {col: collections.deque(maxlen=maxlen) for col in COLS}
lock     = threading.Lock()
last_raw = {}
status_lines = collections.deque(maxlen=6)   # shown in status panel

# Console throttle — only print one [data] line per N seconds
_last_console_print = 0.0
CONSOLE_INTERVAL    = 2.0    # seconds between [data] summary prints


# ── Port detection ────────────────────────────────────────────────────────────
def find_pico_port():
    ports = serial.tools.list_ports.comports()
    for p in ports:
        if p.vid == 0x2E8A:
            print(f"[auto] Found Pico on {p.device}")
            return p.device
    if ports:
        print("Available ports:")
        for i, p in enumerate(ports):
            print(f"  [{i}] {p.device}  {p.description}")
        idx = input("Select port number: ").strip()
        return ports[int(idx)].device
    raise RuntimeError("No serial ports found. Is the Pico connected?")


# ── Serial reader thread ───────────────────────────────────────────────────────
def serial_reader(port):
    global _last_console_print
    try:
        ser = serial.Serial(port, BAUD, timeout=2)
        print(f"[serial] Opened {port} @ {BAUD}")
    except serial.SerialException as e:
        print(f"[ERR] Cannot open {port}: {e}")
        sys.exit(1)

    line_count   = 0
    parse_ok     = 0
    last_health  = time.time()

    while True:
        try:
            raw = ser.readline().decode("utf-8", errors="replace").strip()
        except Exception as e:
            print(f"[serial] readline exception: {e}")
            time.sleep(0.1)
            continue

        if not raw:
            continue

        line_count += 1
        ts_wall = datetime.now().strftime("%H:%M:%S")

        # Firmware debug/error lines
        if raw.startswith("[ERR]") or raw.startswith("==="):
            msg = f"{ts_wall}  {raw}"
            print(f"[fw] {raw}")
            with lock:
                status_lines.append(("err", msg))
            continue

        # Field count gate
        parts = raw.split(",")
        if len(parts) != len(COLS):
            continue
        if parts[0] == "ts_ms":
            continue

        # Parse
        parsed = {}
        ok = True
        for col, val in zip(COLS, parts):
            if val.strip() == "null":
                parsed[col] = None
            else:
                try:
                    parsed[col] = float(val)
                except ValueError:
                    parsed[col] = None
                    ok = False

        if not ok:
            continue

        # Detect PM saturation / obstruction
        pm_sat = any(
            parsed.get(c) is not None and abs(parsed[c] - PM_SATURATED) < 1.0
            for c in ["pm1.0", "pm2.5", "pm4.0", "pm10"]
        )

        # Store — treat saturated PM as None (gap in plot) so it doesn't
        # compress the y-axis and hide real data
        with lock:
            for col in COLS:
                v = parsed.get(col)
                if pm_sat and col in ("pm1.0", "pm2.5", "pm4.0", "pm10"):
                    data[col].append(None)
                else:
                    data[col].append(v)
                    if v is not None:
                        last_raw[col] = v

        parse_ok += 1

        # Build status message
        now = time.time()
        pm_note = "  [PM SATURATED — sensor obstructed?]" if pm_sat else ""
        co2_v   = parsed.get("co2_ppm")
        co2_note = "  [CO2 warming up]" if (co2_v is not None and co2_v < 300) else ""

        # Throttled console summary
        if now - _last_console_print >= CONSOLE_INTERVAL:
            _last_console_print = now
            with lock:
                lr = dict(last_raw)
            print(
                f"[{ts_wall}] "
                f"T={lr.get('temp_C','?'):>5}°C  "
                f"RH={lr.get('rh_%','?'):>5}%  "
                f"CO2={lr.get('co2_ppm','?'):>5}ppm{co2_note}  "
                f"VOC={lr.get('voc_idx','?'):>5}  "
                f"NOx={lr.get('nox_idx','?'):>4}  "
                f"PM2.5={lr.get('pm2.5','?'):>7}{pm_note}"
            )

        # Status panel update (always)
        with lock:
            level = "warn" if (pm_sat or co2_note) else "ok"
            msg = (
                f"{ts_wall}  "
                f"T={parsed.get('temp_C','?')}°C  "
                f"RH={parsed.get('rh_%','?')}%  "
                f"CO2={parsed.get('co2_ppm','?')}ppm  "
                f"VOC={parsed.get('voc_idx','?')}"
                + pm_note + co2_note
            )
            status_lines.append((level, msg))

        # Health every 30 s
        if now - last_health >= 30:
            print(f"[health] lines={line_count}  parsed_ok={parse_ok}  deque={len(data['ts_ms'])}")
            last_health = now
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

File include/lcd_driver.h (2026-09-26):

#pragma once
// ============================================================
//  lcd_driver.h  –  Waveshare Pico-LCD-1.14 low-level driver
//
//  ST7789V, 240x135, RGB565, SPI1
//  Pins (hard-wired on board):
//    GP10 = SCK    GP11 = MOSI   GP9  = CS
//    GP8  = DC     GP12 = RST    GP13 = BL
//
//  Uses a 240×TILE_H tile buffer (9.6 KB) for partial updates.
//  Full screen = 8 tiles; individual regions can be refreshed
//  cheaply by only pushing dirty tiles.
// ============================================================

#include <Arduino.h>
#include <SPI.h>
#include <hardware/gpio.h>

// ---- Pins --------------------------------------------------
#define LCD_SCK   10
#define LCD_MOSI  11
#define LCD_CS     9
#define LCD_DC     8
#define LCD_RST   12
#define LCD_BL    13

// ---- Screen dimensions ------------------------------------
#define LCD_W   240
#define LCD_H   135

// ---- Tile buffer -------------------------------------------
#define TILE_H   20           // rows per tile
#define TILE_BUF_BYTES  (LCD_W * TILE_H * 2)
static uint16_t _tile_buf[LCD_W * TILE_H];

// ---- RGB565 colour helpers ---------------------------------
#define RGB565(r,g,b) ((uint16_t)(((r & 0xF8) << 8) | ((g & 0xFC) << 3) | (b >> 3)))

// Colour palette
#define COL_BLACK    RGB565(  0,   0,   0)
#define COL_WHITE    RGB565(255, 255, 255)
#define COL_AMBER    RGB565(255, 160,   0)   // drawbar active
#define COL_AMBER_DIM RGB565( 60,  38,   0)  // drawbar empty
#define COL_GREEN    RGB565(  0, 200,  60)   // MIDI activity
#define COL_ORANGE   RGB565(255,  80,   0)   // percussion
#define COL_BLUE     RGB565( 40, 120, 255)   // volume
#define COL_GRAY     RGB565( 80,  80,  80)   // labels
#define COL_DARKGRAY RGB565( 30,  30,  30)   // backgrounds
#define COL_RED      RGB565(220,  40,  40)   // click

// ---- SPI helper --------------------------------------------
static SPISettings _lcd_spi_settings(62500000, MSBFIRST, SPI_MODE0);

inline void _lcd_cmd(uint8_t cmd) {
    digitalWrite(LCD_DC, LOW);
    digitalWrite(LCD_CS, LOW);
    SPI1.transfer(cmd);
    digitalWrite(LCD_CS, HIGH);
}

inline void _lcd_data8(uint8_t d) {
    digitalWrite(LCD_DC, HIGH);
    digitalWrite(LCD_CS, LOW);
    SPI1.transfer(d);
    digitalWrite(LCD_CS, HIGH);
}

inline void _lcd_data16(uint16_t d) {
    digitalWrite(LCD_DC, HIGH);
    digitalWrite(LCD_CS, LOW);
    SPI1.transfer16(d);
    digitalWrite(LCD_CS, HIGH);
}

// ---- Set address window ------------------------------------
// ST7789 on Waveshare Pico-LCD-1.14: physical 240x135 sits at
// offset (40,53) within the 240x320 controller framebuffer (landscape)
#define LCD_X_OFFSET  40
#define LCD_Y_OFFSET  53

inline void _lcd_set_window(uint16_t x0, uint16_t y0, uint16_t x1, uint16_t y1) {
    x0 += LCD_X_OFFSET; x1 += LCD_X_OFFSET;
    y0 += LCD_Y_OFFSET; y1 += LCD_Y_OFFSET;
    _lcd_cmd(0x2A);
    digitalWrite(LCD_DC, HIGH); digitalWrite(LCD_CS, LOW);
    SPI1.transfer(x0 >> 8); SPI1.transfer(x0 & 0xFF);
    SPI1.transfer(x1 >> 8); SPI1.transfer(x1 & 0xFF);
    digitalWrite(LCD_CS, HIGH);
    _lcd_cmd(0x2B);
    digitalWrite(LCD_DC, HIGH); digitalWrite(LCD_CS, LOW);
    SPI1.transfer(y0 >> 8); SPI1.transfer(y0 & 0xFF);
    SPI1.transfer(y1 >> 8); SPI1.transfer(y1 & 0xFF);
    digitalWrite(LCD_CS, HIGH);
    _lcd_cmd(0x2C);
}

// ---- Push tile buffer to screen ----------------------------
// Pushes TILE_H rows starting at y_start
inline void lcd_push_tile(uint16_t y_start) {
    uint16_t y_end = y_start + TILE_H - 1;
    if (y_end >= LCD_H) y_end = LCD_H - 1;
    _lcd_set_window(0, y_start, LCD_W - 1, y_end);
    digitalWrite(LCD_DC, HIGH);
    digitalWrite(LCD_CS, LOW);
    // Transfer as bytes (big-endian swap needed: RGB565 high byte first)
    uint32_t n = (uint32_t)(y_end - y_start + 1) * LCD_W;
    for (uint32_t i = 0; i < n; i++) {
        uint16_t px = _tile_buf[i];
        SPI1.transfer(px >> 8);
        SPI1.transfer(px & 0xFF);
    }
    digitalWrite(LCD_CS, HIGH);
}

// ---- Tile buffer pixel write -------------------------------
inline void tile_pixel(uint16_t x, uint16_t tile_y, uint16_t colour) {
    _tile_buf[tile_y * LCD_W + x] = colour;
}

// Fill a rect in the tile buffer (tile_y is local y within tile)
inline void tile_fill_rect(uint16_t x, uint16_t tile_y, uint16_t w, uint16_t h, uint16_t colour) {
    for (uint16_t row = tile_y; row < tile_y + h; row++) {
        for (uint16_t col = x; col < x + w; col++) {
            _tile_buf[row * LCD_W + col] = colour;
        }
    }
}

// Draw a single char (5x7 font, scaled) into tile buffer
// Only supports printable ASCII 32-127
// Font stored as 5 columns of 7 bits
static const uint8_t _font5x7[][5] = {
    {0x00,0x00,0x00,0x00,0x00}, // ' '
    {0x00,0x00,0x5F,0x00,0x00}, // '!'
    {0x00,0x07,0x00,0x07,0x00}, // '"'
    {0x14,0x7F,0x14,0x7F,0x14}, // '#'
    {0x24,0x2A,0x7F,0x2A,0x12}, // '$'
    {0x23,0x13,0x08,0x64,0x62}, // '%'
    {0x36,0x49,0x55,0x22,0x50}, // '&'
    {0x00,0x05,0x03,0x00,0x00}, // '''
    {0x00,0x1C,0x22,0x41,0x00}, // '('
    {0x00,0x41,0x22,0x1C,0x00}, // ')'
    {0x14,0x08,0x3E,0x08,0x14}, // '*'
    {0x08,0x08,0x3E,0x08,0x08}, // '+'
    {0x00,0x50,0x30,0x00,0x00}, // ','
    {0x08,0x08,0x08,0x08,0x08}, // '-'
    {0x00,0x60,0x60,0x00,0x00}, // '.'
    {0x20,0x10,0x08,0x04,0x02}, // '/'
    {0x3E,0x51,0x49,0x45,0x3E}, // '0'
    {0x00,0x42,0x7F,0x40,0x00}, // '1'
    {0x42,0x61,0x51,0x49,0x46}, // '2'
    {0x21,0x41,0x45,0x4B,0x31}, // '3'
    {0x18,0x14,0x12,0x7F,0x10}, // '4'
    {0x27,0x45,0x45,0x45,0x39}, // '5'
    {0x3C,0x4A,0x49,0x49,0x30}, // '6'
    {0x01,0x71,0x09,0x05,0x03}, // '7'
    {0x36,0x49,0x49,0x49,0x36}, // '8'
    {0x06,0x49,0x49,0x29,0x1E}, // '9'
    {0x00,0x36,0x36,0x00,0x00}, // ':'
    {0x00,0x56,0x36,0x00,0x00}, // ';'
    {0x08,0x14,0x22,0x41,0x00}, // '<'
    {0x14,0x14,0x14,0x14,0x14}, // '='
    {0x00,0x41,0x22,0x14,0x08}, // '>'
    {0x02,0x01,0x51,0x09,0x06}, // '?'
    {0x32,0x49,0x79,0x41,0x3E}, // '@'
    {0x7E,0x11,0x11,0x11,0x7E}, // 'A'
    {0x7F,0x49,0x49,0x49,0x36}, // 'B'
    {0x3E,0x41,0x41,0x41,0x22}, // 'C'
    {0x7F,0x41,0x41,0x22,0x1C}, // 'D'
    {0x7F,0x49,0x49,0x49,0x41}, // 'E'
    {0x7F,0x09,0x09,0x09,0x01}, // 'F'
    {0x3E,0x41,0x49,0x49,0x7A}, // 'G'
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
};

// Draw char at tile-local y, scale 1 or 2
inline void tile_char(uint16_t x, uint16_t ty, char c, uint16_t fg, uint16_t bg, uint8_t scale=2) {
    if (c < 32 || c > 126) c = '?';
    const uint8_t* glyph = _font5x7[c - 32];
    for (int col = 0; col < 5; col++) {
        uint8_t bits = glyph[col];
        for (int row = 0; row < 7; row++) {
            uint16_t colour = (bits >> row) & 1 ? fg : bg;
            for (int sy = 0; sy < scale; sy++)
                for (int sx = 0; sx < scale; sx++)
                    tile_pixel(x + col*scale + sx, ty + row*scale + sy, colour);
        }
    }
}
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

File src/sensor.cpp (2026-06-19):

#include "sensor.h"
#include "globals.h"
#include <Wire.h>

#ifdef NO_ERROR
  #undef NO_ERROR
#endif
#define NO_ERROR 0

SensirionI2cSen66 sen66;
Measurement       latest;

static char errMsg[64];

static void printError(const char* label, int16_t err) {
    errorToString(err, errMsg, sizeof(errMsg));
    Serial.printf("[ERR] %s: %s\n", label, errMsg);
}

void initSensor(bool doFanCleaning) {
    Wire.setSDA(4);
    Wire.setSCL(5);
    Wire.begin();

    // I2C scan — confirm SEN66 is actually visible on the bus
    Serial.println("[sen66] I2C scan...");
    bool found = false;
    for (uint8_t addr = 1; addr < 127; addr++) {
        Wire.beginTransmission(addr);
        if (Wire.endTransmission() == 0) {
            Serial.printf("[sen66]   device at 0x%02X\n", addr);
            if (addr == SEN66_I2C_ADDR_6B) found = true;
        }
    }
    if (!found) {
        Serial.printf("[sen66] WARNING: nothing at expected addr 0x%02X!\n", SEN66_I2C_ADDR_6B);
    }

    sen66.begin(Wire, SEN66_I2C_ADDR_6B);

    int16_t err = sen66.deviceReset();
    if (err != NO_ERROR) { printError("deviceReset", err); }
    else { Serial.println("[sen66] deviceReset OK"); }
    delay(1200);

    err = sen66.startContinuousMeasurement();
    if (err != NO_ERROR) {
        printError("startMeasurement", err);
        Serial.println("[sen66] FATAL: measurement not started — fan/gas sensors will not work");
    } else {
        Serial.println("[sen66] startContinuousMeasurement OK");
    }

    if (doFanCleaning) {
        err = sen66.startFanCleaning();
        if (err != NO_ERROR) {
            printError("fanCleaning", err);
        } else {
            Serial.println("[sen66] startFanCleaning OK — fan should be audible now");
        }
        Serial.print("[sen66] Fan cleaning ");
        for (int i = 0; i < 10; i++) {
            delay(1000);
            Serial.print(".");
        }
        Serial.println(" done");
    }
    Serial.println("[sen66] Ready");
}

bool readSensor(Measurement& m) {
    bool    dataReady = false;
    uint8_t padding   = 0;

    int16_t err = sen66.getDataReady(padding, dataReady);
    if (err != NO_ERROR) { printError("getDataReady", err); return false; }
    if (!dataReady) {
        if (DBG_SENSOR) Serial.println("[sensor] dataReady=false, skipping");
        return false;
    }

    uint16_t pm1Raw, pm25Raw, pm4Raw, pm10Raw;
    int16_t  rhRaw, tempRaw, vocRaw, noxRaw;
    uint16_t co2Raw;

    err = sen66.readMeasuredValuesAsIntegers(
        pm1Raw, pm25Raw, pm4Raw, pm10Raw,
        rhRaw, tempRaw, vocRaw, noxRaw, co2Raw);
    if (err != NO_ERROR) { printError("readMeasured", err); return false; }

    m.ts_ms = millis();
    m.rh    = rhRaw   / 100.0f;
    m.temp  = tempRaw / 200.0f;
    m.voc   = (vocRaw  == INT16_INVALID)  ? 0.0f : vocRaw  / 10.0f;
    m.nox   = (noxRaw  == INT16_INVALID)  ? 0.0f : noxRaw  / 10.0f;
    m.co2   = (co2Raw  == UINT16_INVALID) ? 0     : co2Raw;

    bool pmInvalid = (pm1Raw == UINT16_INVALID);
    float pm1  = pmInvalid ? 0.0f : pm1Raw  / 10.0f;
    float pm25 = pmInvalid ? 0.0f : pm25Raw / 10.0f;
    float pm4  = pmInvalid ? 0.0f : pm4Raw  / 10.0f;
    float pm10 = pmInvalid ? 0.0f : pm10Raw / 10.0f;
    m.pm_sat = (!pmInvalid) && (fabsf(pm25 - PM_SATURATED) < 1.0f);
    m.pm1 = pm1; m.pm25 = pm25; m.pm4 = pm4; m.pm10 = pm10;
    m.valid = true;

    if (DBG_SENSOR) {
        Serial.printf("[sensor] T=%.2f RH=%.1f CO2=%u VOC=%.0f NOx=%.0f PM2.5=%s\n",
            m.temp, m.rh, m.co2, m.voc, m.nox,
            m.pm_sat ? "SAT" : String(m.pm25, 1).c_str());
    }
    return true;
}

void printReadable(const Measurement& m) {
    Serial.printf(
        "[read] T=%.2f°C  RH=%.1f%%  CO2=%uppm  VOC=%.0f  NOx=%.0f"
        "  PM2.5=%s  uptime=%lus\n",
        m.temp, m.rh, m.co2, m.voc, m.nox,
        m.pm_sat ? "SAT" : String(m.pm25, 1).c_str(),
        millis() / 1000);
}

void printMeasurement(const Measurement& m) {
    char s1[10], s2[10], s3[10], s4[10];
    if (m.pm_sat) {
        strcpy(s1,"null"); strcpy(s2,"null");
        strcpy(s3,"null"); strcpy(s4,"null");
    } else {
        dtostrf(m.pm1,  1, 1, s1); dtostrf(m.pm25, 1, 1, s2);
        dtostrf(m.pm4,  1, 1, s3); dtostrf(m.pm10, 1, 1, s4);
    }
    Serial.printf("%lu,%s,%s,%s,%s,%.1f,%.2f,%.1f,%.1f,%u\n",
        m.ts_ms, s1, s2, s3, s4,
        m.rh, m.temp, m.voc, m.nox, m.co2);
}

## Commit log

2026-06-06 lora addition not working yet
    [http_server.cpp, lora_wan.cpp]
2026-09-26 in between version, lora killed, screen with SPI bus release
    [box.scad, box.stl, lid.stl]
